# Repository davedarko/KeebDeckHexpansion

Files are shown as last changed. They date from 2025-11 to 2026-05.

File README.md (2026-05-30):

# Keebdexpansion

A keyboard hexpansion for the [Tildagon badge](https://tildagon.badge.emfcamp.org/) using the [solder.party KeebDeck Keyboard](https://www.solder.party/docs/keebdeck/keyboard/). Software for the hexpansion is [provided by @sodoku](https://github.com/sodoku/tildagon-keebdexpansion).

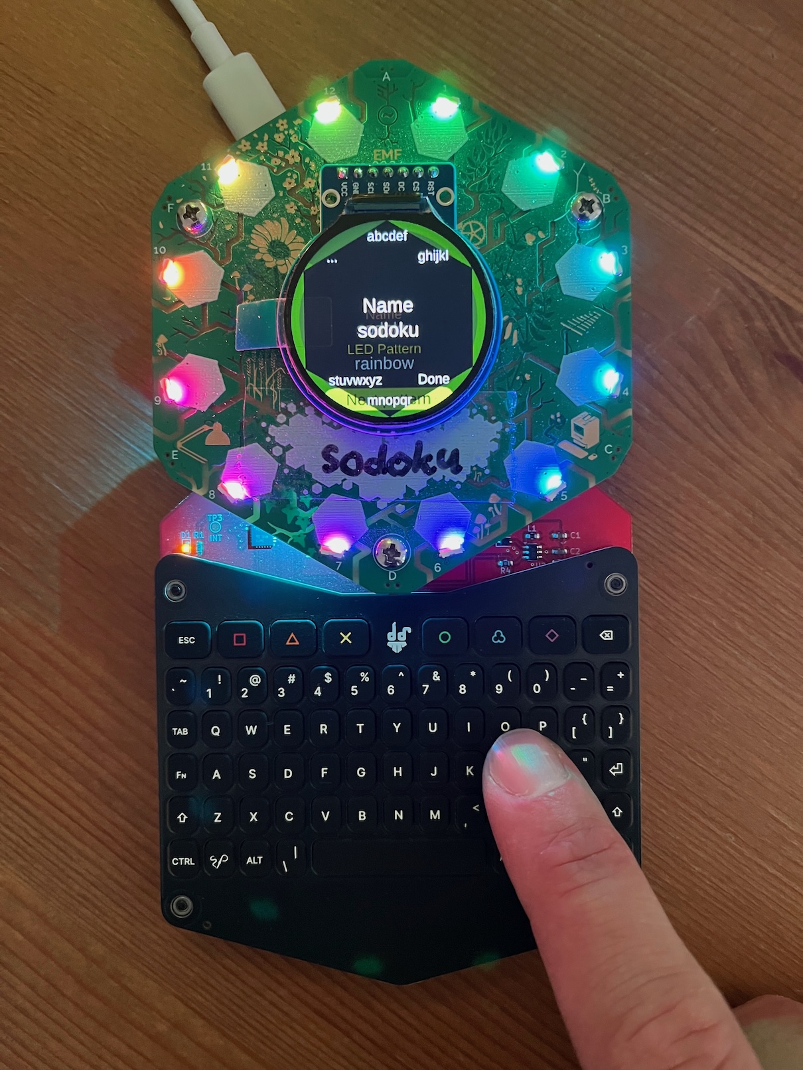
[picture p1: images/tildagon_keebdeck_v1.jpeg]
Keepdexpansion V1 connected to the Tildagon


## Features

- Full layout keyboard
- RGB-Backlit keys
- Type in text inputs

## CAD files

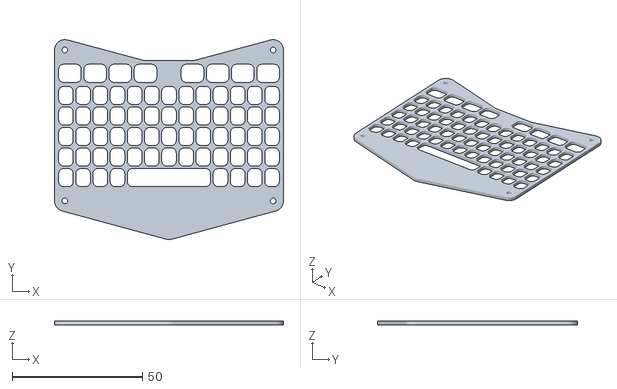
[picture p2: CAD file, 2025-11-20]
KiCad/frontplate/frontplate.stl
88.0 x 76.8 x 1.51

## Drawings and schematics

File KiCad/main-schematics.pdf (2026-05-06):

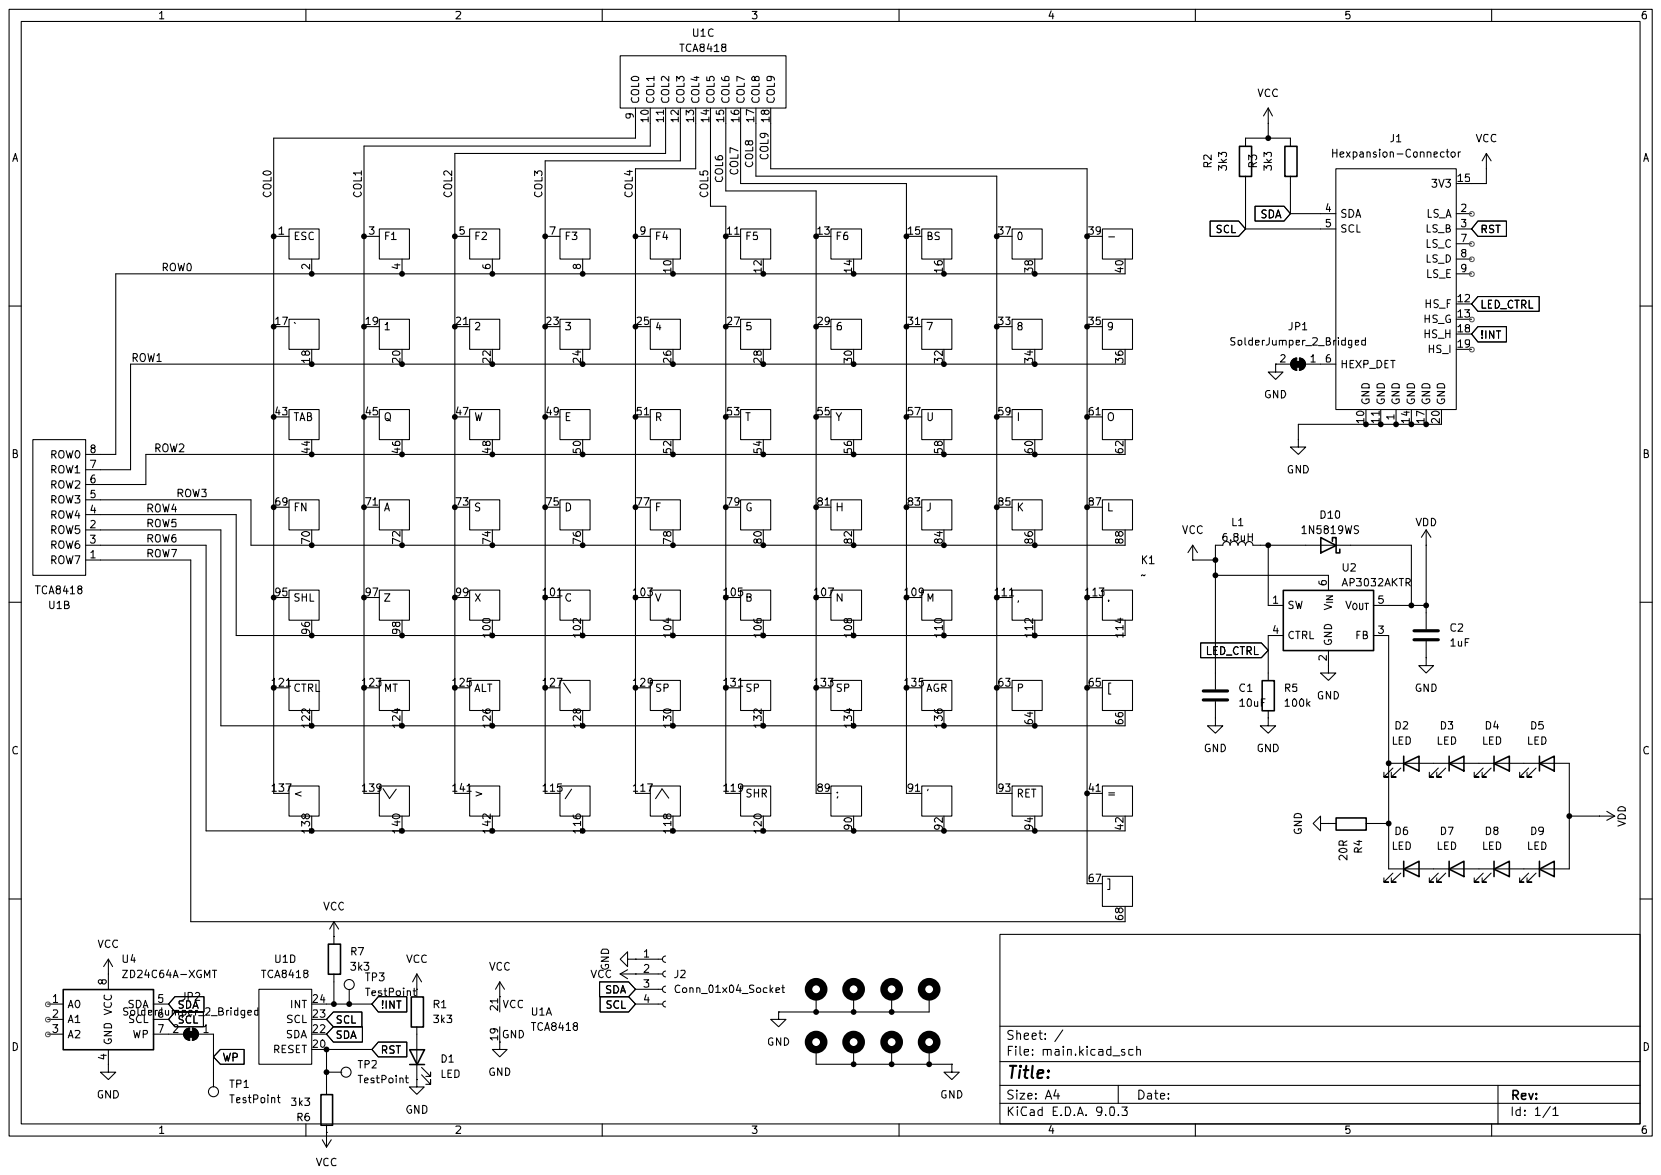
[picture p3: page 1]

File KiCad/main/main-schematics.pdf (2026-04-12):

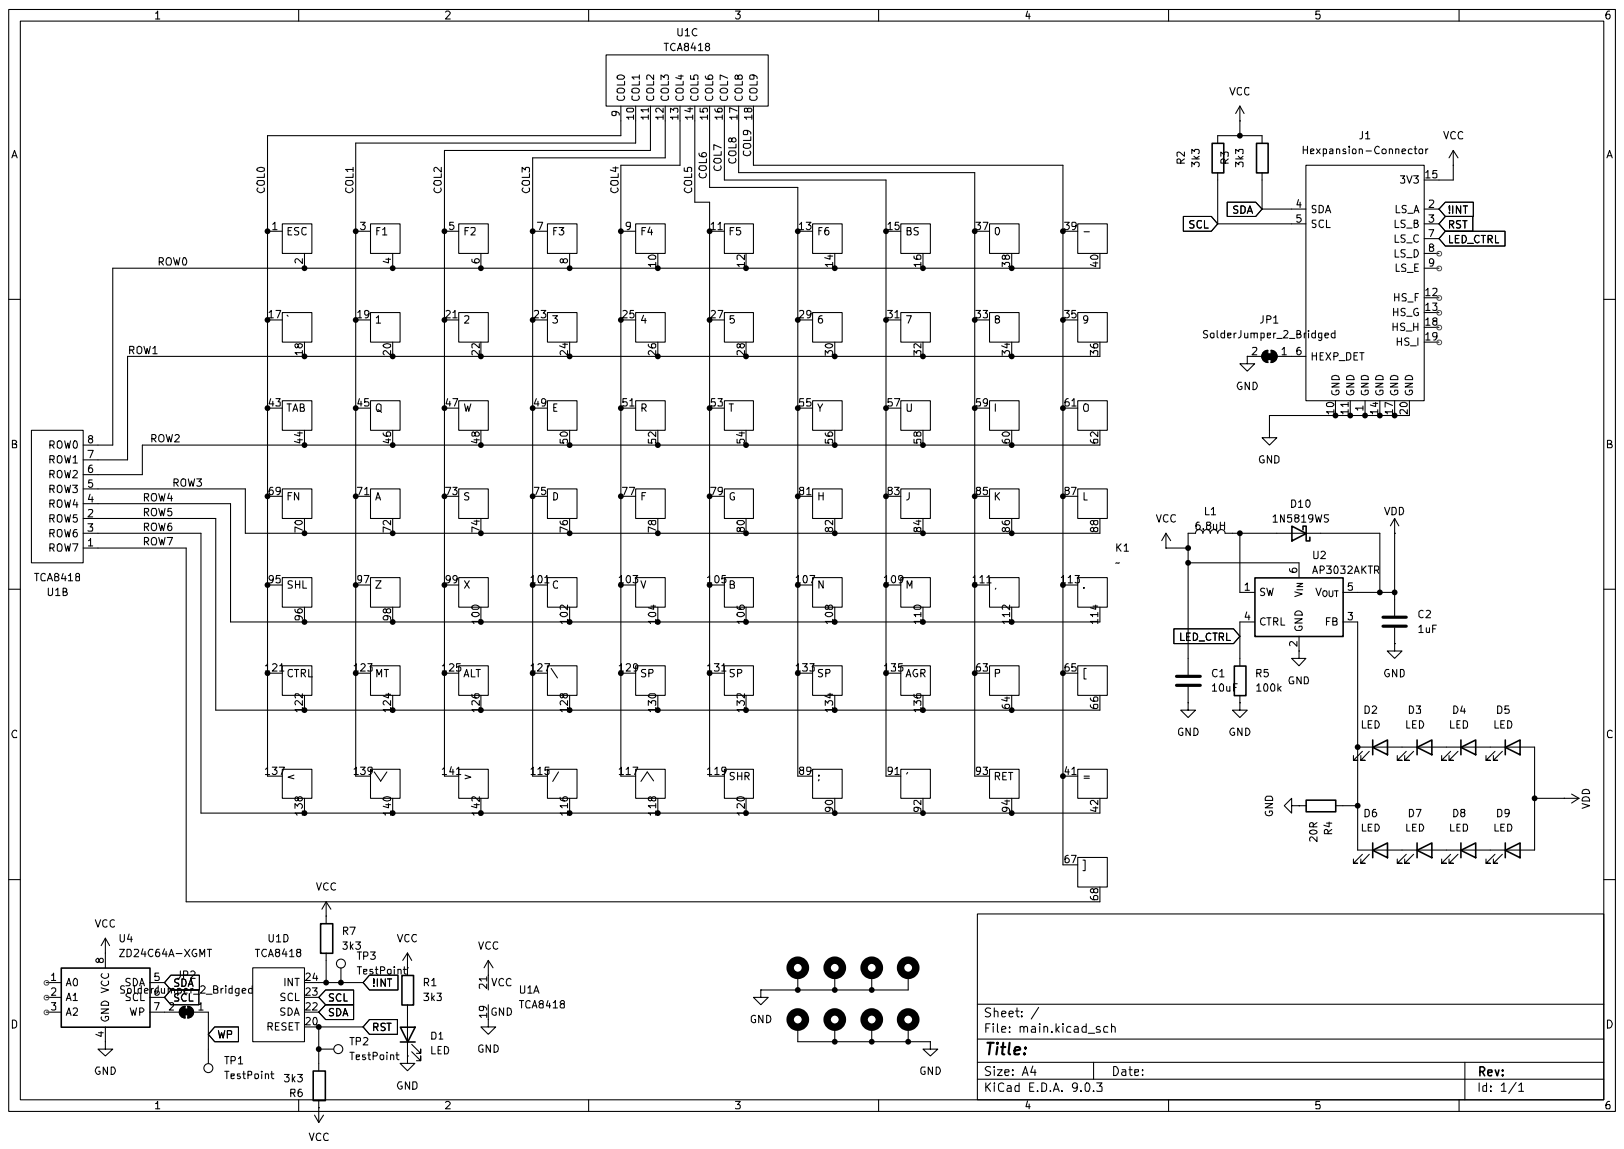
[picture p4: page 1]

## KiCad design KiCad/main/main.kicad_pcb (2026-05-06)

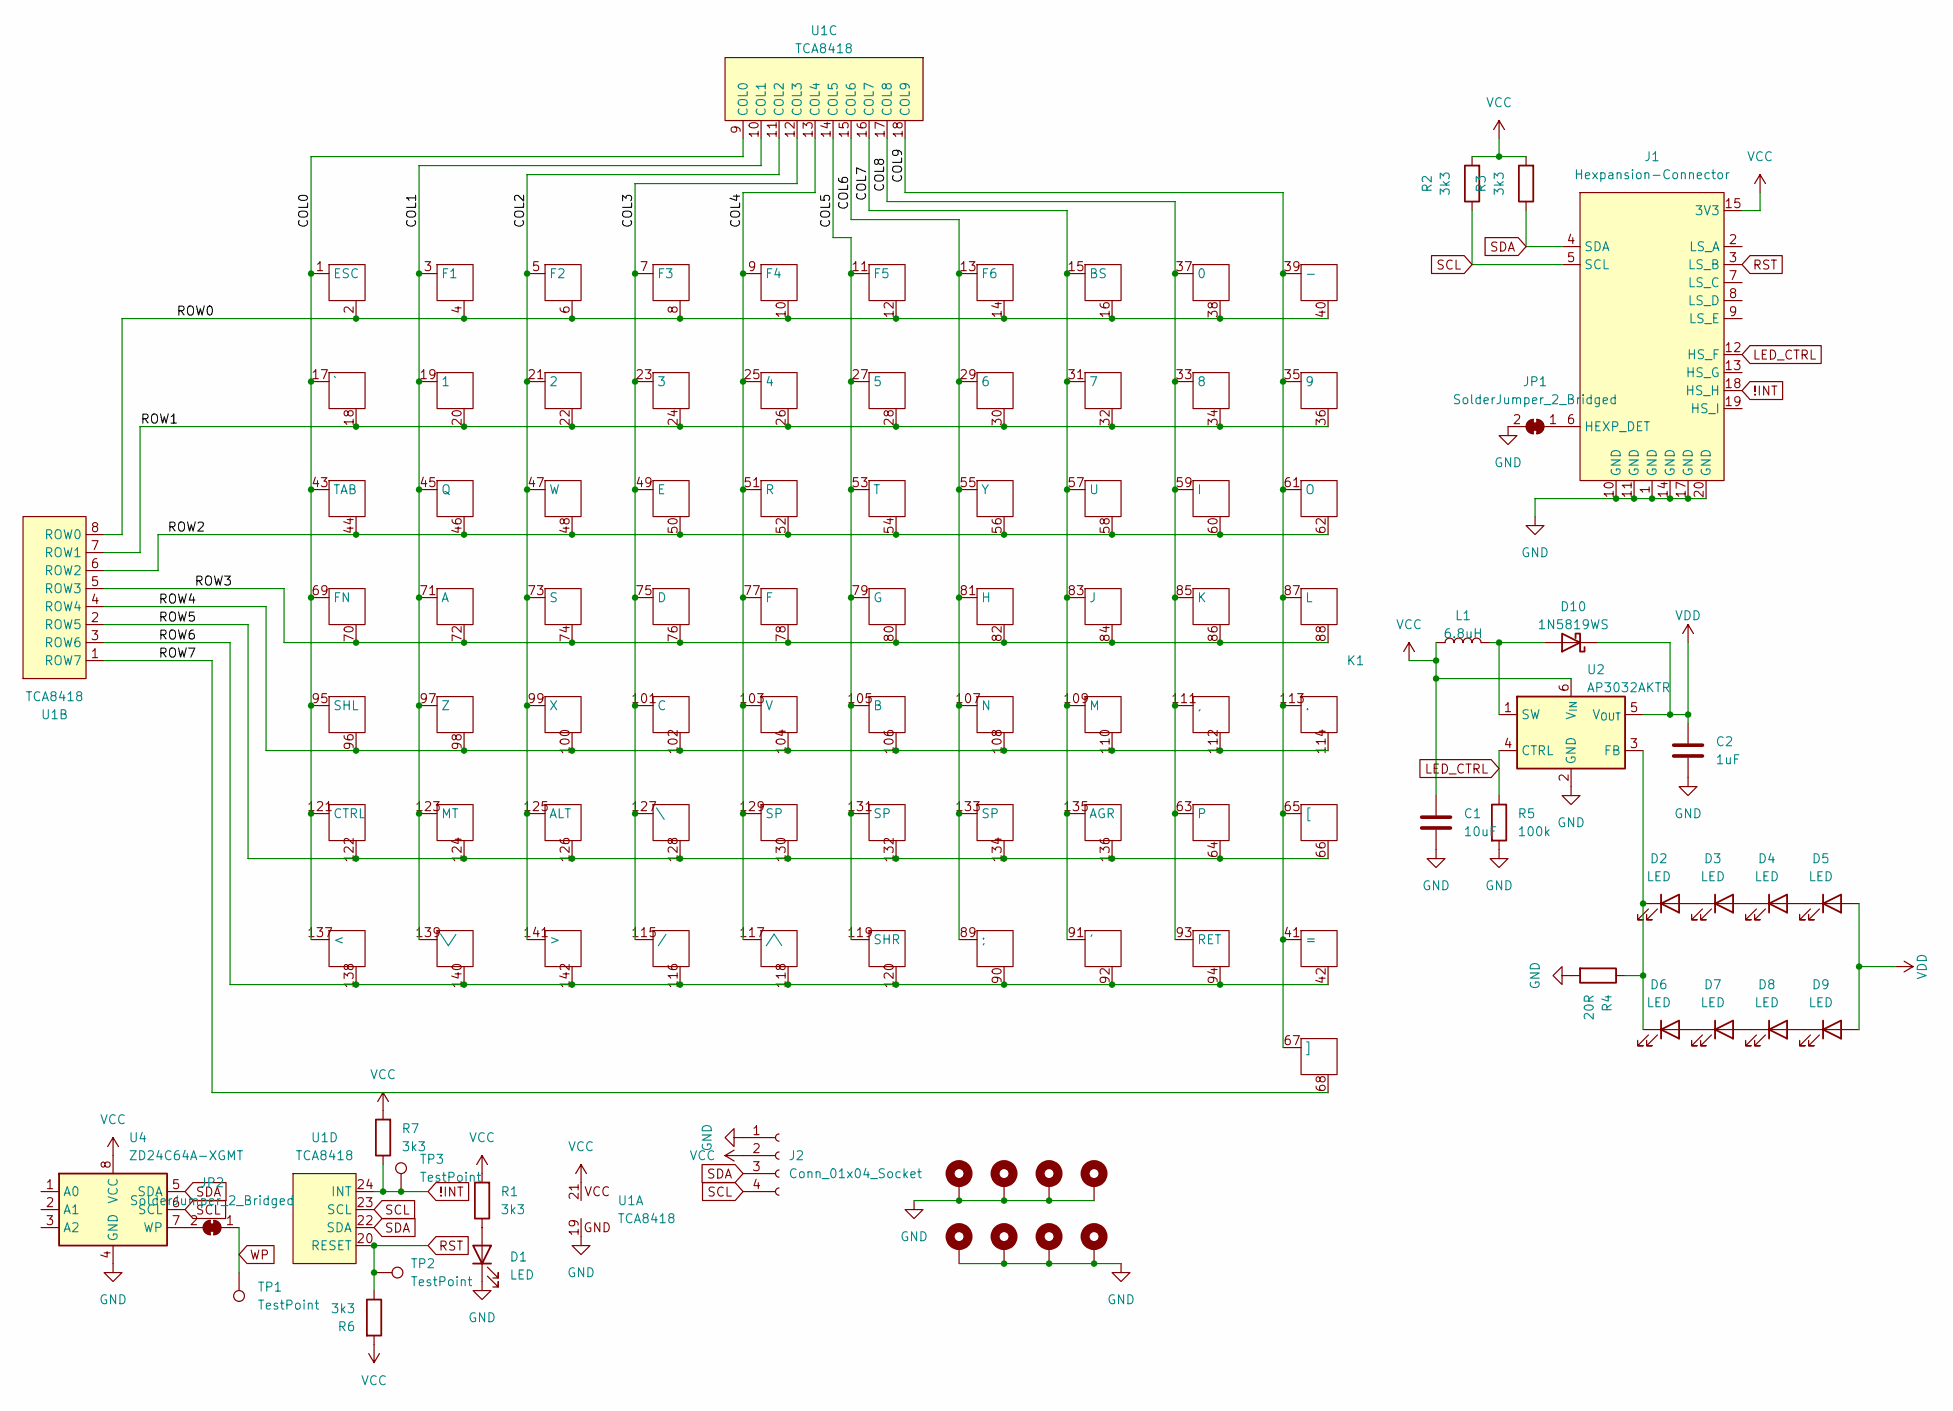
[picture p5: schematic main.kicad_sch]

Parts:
C1: 10uF; C_0603_1608Metric_Pad1.08x0.95mm_HandSolder
C2: 1uF; C_0603_1608Metric_Pad1.08x0.95mm_HandSolder
D1: LED; LED_0603_1608Metric_Pad1.05x0.95mm_HandSolder
D2, D3, D4, D5, D6, D7, D8, D9: LED; LTW-010DCG; LCSC C575429
D10: 1N5819WS; D_SOD-323
H1, H2, H3, H4: MountingHole_Pad; MountingHole_2.2mm_M2_Pad_Via
H5, H6, H7, H8: MountingHole_Pad; MountingHole_2.2mm_M2_Pad_Via; LCSC C2915626
J1: Hexpansion-Connector; hexpansion-edge-connector
J2: Conn_01x04_Socket; JST_SH_SM04B-SRSS-TB_1x04-1MP_P1.00mm_Horizontal
JP1, JP2: SolderJumper_2_Bridged; SolderJumper-2_P1.3mm_Bridged_RoundedPad1.0x1.5mm
K1: keyboard_arturo182
L1: 6.8uH; L_0603_1608Metric_Pad1.05x0.95mm_HandSolder
R1, R2, R3, R6, R7: 3k3; R_0603_1608Metric_Pad0.98x0.95mm_HandSolder
R4: 20R; R_0603_1608Metric_Pad0.98x0.95mm_HandSolder
R5: 100k; R_0603_1608Metric_Pad0.98x0.95mm_HandSolder
TP1, TP2, TP3: TestPoint; TestPoint_Pad_D1.5mm
U1: TCA8418; QFN50P400X400X80-25N
U2: AP3032AKTR; SOT-23-6; LCSC C264086
U4: ZD24C64A-XGMT; TSSOP-8_4.4x3mm_P0.65mm; MPN C2875852

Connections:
!INT: J1.18 (HS_H), R7.1, TP3.1, U1.24 (INT)
/COL0: K1.1 (ESC), K1.17 (`), K1.43 (TAB), K1.69 (FN), K1.95 (SHL), K1.121 (CTRL), K1.137 (<), U1.9 (COL0)
/COL1: K1.3 (F1), K1.19 (1), K1.45 (Q), K1.71 (A), K1.97 (Z), K1.123 (MT), K1.139 (\/), U1.10 (COL1)
/COL2: K1.5 (F2), K1.21 (2), K1.47 (W), K1.73 (S), K1.99 (X), K1.125 (ALT), K1.141 (>), U1.11 (COL2)
/COL3: K1.7 (F3), K1.23 (3), K1.49 (E), K1.75 (D), K1.101 (C), K1.115 (/), K1.127 (\), U1.12 (COL3)
/COL4: K1.9 (F4), K1.25 (4), K1.51 (R), K1.77 (F), K1.103 (V), K1.117 (/\), K1.129 (SP), U1.13 (COL4)
/COL5: K1.11 (F5), K1.27 (5), K1.53 (T), K1.79 (G), K1.105 (B), K1.119 (SHR), K1.131 (SP), U1.14 (COL5)
/COL6: K1.13 (F6), K1.29 (6), K1.55 (Y), K1.81 (H), K1.89 (;), K1.107 (N), K1.133 (SP), U1.15 (COL6)
/COL7: K1.15 (BS), K1.31 (7), K1.57 (U), K1.83 (J), K1.91 ('), K1.109 (M), K1.135 (AGR), U1.16 (COL7)
/COL8: K1.33 (8), K1.37 (0), K1.59 (I), K1.63, K1.85 (K), K1.93 (RET), K1.111 (,), U1.17 (COL8)
/COL9: K1.35 (9), K1.39 (-), K1.41 (=), K1.61 (O), K1.65 ([), K1.67 (]), K1.87 (L), K1.113 (.), U1.18 (COL9)
/ROW0: K1.2, K1.4, K1.6, K1.8, K1.10, K1.12, K1.14, K1.16, K1.38, K1.40, U1.8 (ROW0)
/ROW1: K1.18, K1.20, K1.22, K1.24, K1.26, K1.28, K1.30, K1.32, K1.34, K1.36, U1.7 (ROW1)
/ROW2: K1.44, K1.46, K1.48, K1.50, K1.52, K1.54, K1.56, K1.58, K1.60, K1.62, U1.6 (ROW2)
/ROW3: K1.70, K1.72, K1.74, K1.76, K1.78, K1.80, K1.82, K1.84, K1.86, K1.88, U1.5 (ROW3)
/ROW4: K1.96, K1.98, K1.100, K1.102, K1.104, K1.106, K1.108, K1.110, K1.112, K1.114, U1.4 (ROW4)
/ROW5: K1.64, K1.66, K1.122, K1.124, K1.126, K1.128, K1.130, K1.132, K1.134, K1.136, U1.2 (ROW5)
/ROW6: K1.42, K1.90, K1.92, K1.94, K1.116, K1.118, K1.120, K1.138, K1.140, K1.142, U1.3 (ROW6)
/ROW7: K1.68, U1.1 (ROW7)
GND: C1.2, C2.2, D1.1 (K), H1.1, H2.1, H3.1, H4.1, H5.1, H6.1, H7.1, H8.1, J1.1 (GND), J1.10 (GND), J1.11 (GND), J1.14 (GND), J1.17 (GND), J1.20 (GND), J2.1, JP1.2 (B), R4.2, R5.2, U1.19, U2.2 (GND), U4.4 (GND)
LED_CTRL: J1.12 (HS_F), R5.1, U2.4 (CTRL)
unnamed: D1.2 (A), R1.1
unnamed: D2.2 (A), D3.1 (K)
unnamed: D2.1 (K), D6.1 (K), R4.1, U2.3 (FB)
unnamed: D3.2 (A), D4.1 (K)
unnamed: D4.2 (A), D5.1 (K)
unnamed: D6.2 (A), D7.1 (K)
unnamed: D7.2 (A), D8.1 (K)
unnamed: D8.2 (A), D9.1 (K)
unnamed: D10.2 (A), L1.2, U2.1 (SW)
unnamed: J1.6 (HEXP_DET), JP1.1 (A)
unnamed: JP2.2 (B), U4.7 (WP)
RST: J1.3 (LS_B), R6.1, TP2.1, U1.20 (RESET)
SCL: J1.5 (SCL), J2.4, R2.1, U1.23 (SCL), U4.6 (SCL)
SDA: J1.4 (SDA), J2.3, R3.1, U1.22 (SDA), U4.5 (SDA)
VCC: C1.1, J1.15 (3V3), J1.16 (3V3), J2.2, L1.1, R1.2, R2.2, R3.2, R6.2, R7.2, U1.21, U2.6 (V_{IN}), U4.8 (VCC)
VDD: C2.1, D5.2 (A), D9.2 (A), D10.1 (K), U2.5 (V_{OUT})
WP: JP2.1 (A), TP1.1

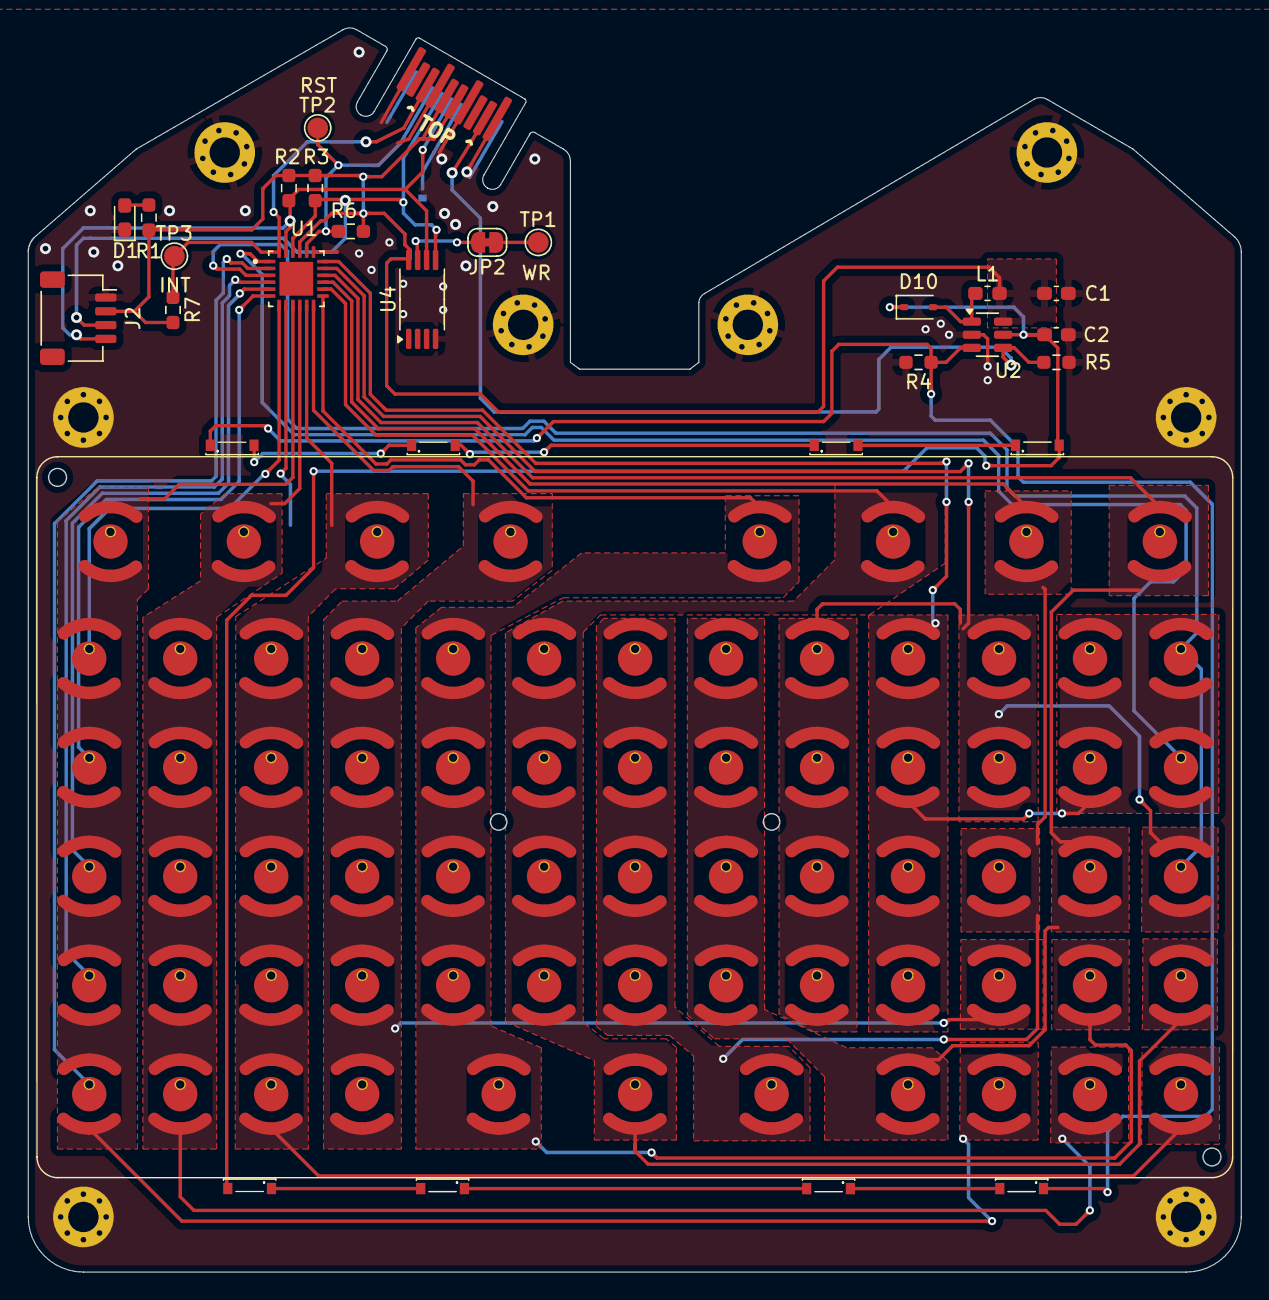
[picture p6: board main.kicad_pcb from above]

Board: 2 copper layers, 88.0 x 90.3 mm, 39 parts (1 on the bottom side), 38 nets.

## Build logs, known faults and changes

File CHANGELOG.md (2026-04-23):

# Changelog

## Revision 3 (WIP)

- switch back to high speed pins

## Revision 2

- switch to low speed pins
- keyboard works only with polling
- leds working (no dimming)
- new working eeprom

## Revision 1

- keyboard fully functional using interupt
- eeprom unsupported
- leds pin connection missing
- reset pin connection missing

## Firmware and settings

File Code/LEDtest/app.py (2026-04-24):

import app
import math
from machine import PWM, Pin
from system.hexpansion.config import HexpansionConfig

class LEDTestApp(app.App):
    def __init__(self):
        
        self.hexpansion_config = HexpansionConfig(4)
        self.pins = {}
        self.step = 0
        self.toggle = 0
        self.pwmval = 0

        # eGPIO pins
        self.pins["ls_1"] = self.hexpansion_config.ls_pin[0]

        # GPIO pins
        self.pins["hs_1"] = self.hexpansion_config.pin[0]
        self.pins["hs_2"] = self.hexpansion_config.pin[1]

        # All pins start in inputs mode. Initialize them as follows:
        self.pins["hs_1"].init(self.pins["hs_1"].OUT)

        # Only LS pins support the PWM function directly.
        self.pins["ls_1"].init(self.pins["ls_1"].PWM)

        self.pwm = PWM(self.pins["hs_2"], freq=120, duty_u16=8192); # Pin(14)

    def update(self, delta):
        self.step = self.step + delta
        if self.step >= 200:
            self.step = 0
            self.pwmval = (self.pwmval+1) * 2 - 1
            if self.pwmval >= 256:
                self.pwmval = 0

            self._toggle_pins()

    def _toggle_pins(self):
        self.pins["ls_1"].duty(self.pwmval)

        if self.pins["hs_1"].value() == 1:
            self.pins["hs_1"].off()
            self.pwm.duty_u16(32768)
            self.toggle = 1
        else:
            self.pins["hs_1"].on()
            self.pwm.duty_u16(8192)
            self.toggle = 0

    def draw(self, ctx):
        ctx.save()
        if self.toggle:
            ctx.rgb(0.9, 0.6, 0.2).rectangle(-120, -120, 240, 240).fill()
        else:
            ctx.rgb(0.2, 0.9, 0.6).rectangle(-120, -120, 240, 240).fill()
        ctx.restore()


__app_export__ = LEDTestApp

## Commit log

2025-11-20 deploy design files V0.1
    [frontplate.kicad_pcb, frontplate.kicad_sch, frontplate.stl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]
2026-01-08 fixed missing connections and changed eeprom
    [main.kicad_pcb, main.kicad_sch]
2026-04-12 Updated board designs to mirror hardware choices
    [main.kicad_pcb, main.kicad_sch]
2026-04-24 Test App for PWM LED control
    [main.kicad_sch]
2026-05-06 Revert "Test App for PWM LED control"
    This reverts commit 16f5d63235216fa5ad93ad454a595f19e9ea91df.
    [main.kicad_sch]
